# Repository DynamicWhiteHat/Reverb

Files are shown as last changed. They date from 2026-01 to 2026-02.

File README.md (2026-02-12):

# Reverb
A custom record player. Place a disk and have it play. Original idea by AKZ Dev on YouTube.

## Features:
- ESP32 S3 Wroom 1 SoM
- 8Ω 10W Speaker
- Disks correspond to songs through an RFID reader
- Gesture sensor for touch-free volume control
- Working stylus that can start and stop music
- 3x8 audio visualizer array
- 2x USB out: 3.0 A at 5V

## Why I designed this project

I saw [this](https://www.youtube.com/watch?v=fBjv4E7mpA4) video on YouTube one day, and I wanted to make my own version. He used an RPi Zero with other modules. I decided that I wanted to improve on this design by making a custom ESP32-based PCB, a built in speaker, and other small features. I also found another video about an ESP32 speaker with an audio visualizer, so I decided to add that through a 3x8 neopixel array. I have gotten better at routing PCBs as a result of this project, and I have also gained a sense of how to make good-looking PCB layouts.

## Image gallery:
<table align="center">
  <tr>
    <td align="center">
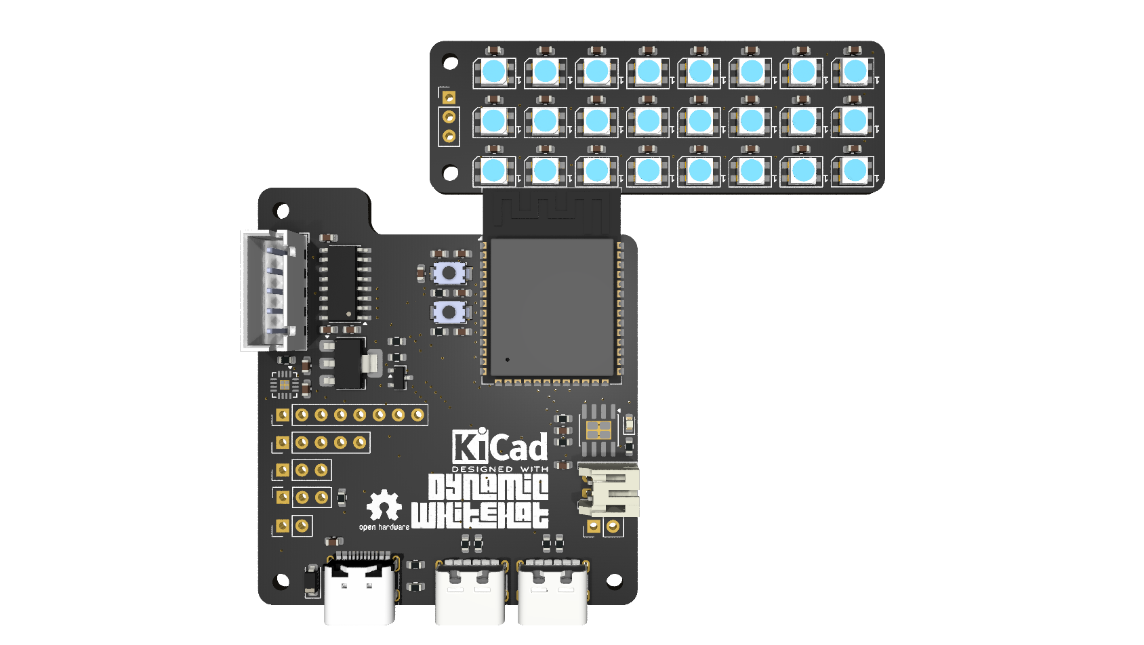
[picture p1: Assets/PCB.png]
      
    </td>
    <td align="center">
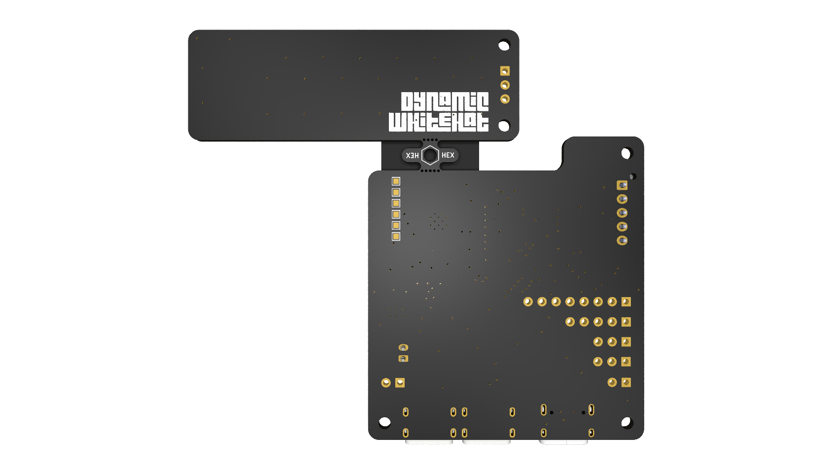
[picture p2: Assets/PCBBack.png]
      
    </td>
  </tr>
  <tr>
    <td align="center" colspan="2">
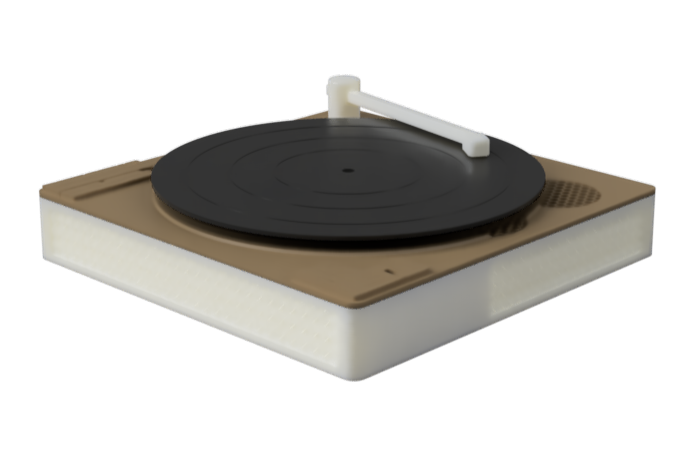
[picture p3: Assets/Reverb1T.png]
      
    </td>
  </tr>
</table>

## Schematic, PCB, And Layout
<table align="center">
  <tr>
    <td align="center" colspan="2">
      Schematic-1
    </td>
  </tr>
  <tr>
    <td align="center">
      
    </td>
    <td align="center">
      
    </td>
  </tr>
  <tr>
    <td align="center" colspan="2">
      ReverbO
    </td>
  </tr>
  <tr>
    <td align="center" colspan="2">
     
    </td>
  </tr>
</table>

## How It Works
The main control board is based on an ESP32-S3 Wroom 1, which is Wifi and Bluetooth enabled. This allows me to connect the SoM to my phone or other device running Spotify. Using the web API, I can control music that plays from my device. Reverb also uses a MAX98357A I2S amplifier that is wired to an 8Ω 10W speaker, allowing audio playback from the music player instead of the device. Additionally, a 3x8 SK6812 Mini NeoPixel array is mounted on the front of the case with a thin wall, allowing audio playback to be visualized. The PAJ7620U2 gesture sensor, located under the REVERB logo on the case, can detect gestures to increase or decrease volume, skip tracks, and perform other tasks. Finally, the main component in the whole design is the RC522 RFID sensor, which picks up data from the RFID stickers located within the 3D printed disks. This allows each disk to be mapped to a song, allowing playback that feels real.

## Bill Of Materials
| Item | Quantity | Link | Price  | Comment |
|---|---|---|---|---|
| JLCPCB Order | 1 | Quote | $23.62 | PCB+Stencil |
| LCSC Order | 1 | See LCSC BOM | $28.00 | PCB Parts |
| Stepper Motor | 1 | https://www.aliexpress.us/item/2251832816516054.html | $2.61  | |
| RC522 RFID Reader | 1 | https://www.aliexpress.us/item/3256805262944828.html | $1.46  | |
| RFID Tag | 1 Pack of 30 | https://www.aliexpress.us/item/3256807346917359.html | $2.92  | |
| PAJ7620U2 Gesture Sensor  | 1 | https://www.aliexpress.us/item/3256803918726745.html | $5.09  | |
| Speaker | 1 | https://www.aliexpress.us/item/3256806860528919.html | $8.12  | |
| Power Switch | 1 Pack of 5  | https://www.aliexpress.us/item/3256803938436290.html | $2.12  | |
| SD Card Reader | 1 | https://www.aliexpress.us/item/3256805115720436.html | $0.83  | |
| US5881 Hall Effect Sensor | 1 Pack of 10 | https://www.aliexpress.us/item/3256806135616417.html | $1.82  | |
| M2-M5 Screw Set | 1 | https://www.amazon.com/mxuteuk-Assortment-Machine-Washers-Printing/dp/B0FM3G5K6H/?th=1 | $9.99  | From Amazon as AliExpress doesn't sell assortments |
| | | | $86.58 | |

### LCSC Bill Of Materials
| LCSC | | | | | | | |
|---|---|---|---|---|---|---|---|
| Description | Quantity Needed | Mrf# | Minimum Order Qty. | Unit Price(USD) | Ext.Price(USD) | LCSC# | Product Link |
| 100nF ±10% 50V Ceramic Capacitor X7R 0603 | 28 | CC0603KRX7R9BB104 | 100 | 0.0021 | 0.21 | C14663 | https://www.lcsc.com/product-detail/C14663.html |
| 10kΩ ±1% 100mW 0603 Thick Film Resistor | 3 | 0603WAF1002T5E | 100 | 0.0011 | 0.11 | C25804 | https://www.lcsc.com/product-detail/C25804.html |
| 10uF ±10% 10V Ceramic Capacitor X5R 0603 | 5 | CL10A106KP8NNNC | 50 | 0.0065 | 0.33 | C19702 | https://www.lcsc.com/product-detail/C19702.html |
| 1MΩ ±1% 100mW 0603 Thick Film Resistor | 2 | 0603WAF1004T5E | 100 | 0.0011 | 0.11 | C22935 | https://www.lcsc.com/product-detail/C22935.html |
| Diode Independent 40V 1A Surface Mount SOD-123 | 1 | K1N5819HW-7-F | 50 | 0.0133 | 0.67 | C2891704 | https://www.lcsc.com/product-detail/C2891704.html |
| 1kΩ ±1% 100mW 0603 Thick Film Resistor | 1 | 0603WAF1001T5E | 100 | 0.0012 | 0.12 | C21190 | https://www.lcsc.com/product-detail/C21190.html |
| 1uF ±10% 50V Ceramic Capacitor X5R 0603 | 1 | CL10A105KB8NNNC | 50 | 0.0056 | 0.28 | C15849 | https://www.lcsc.com/product-detail/C15849.html |
| 22uF ±20% 6.3V Ceramic Capacitor X5R 0603 | 1 | CL10A226MQ8NRNC | 20 | 0.0094 | 0.19 | C59461 | https://www.lcsc.com/product-detail/C59461.html |
| 4.7kΩ ±1% 100mW 0603 Thick Film Resistor | 4 | 0603WAF4701T5E | 100 | 0.0011 | 0.11 | C23162 | https://www.lcsc.com/product-detail/C23162.html |
| 4.7uF ±10% 16V Ceramic Capacitor X5R 0603 | 2 | CL10A475KO8NNNC | 10 | 0.0102 | 0.10 | C19666 | https://www.lcsc.com/product-detail/C19666.html |
| 5.1kΩ ±1% 100mW 0603 Thick Film Resistor | 2 | 0603WAF5101T5E | 100 | 0.0011 | 0.11 | C23186 | https://www.lcsc.com/product-detail/C23186.html |
| 634kΩ ±1% 100mW 0603 Thick Film Resistor | 1 | 0603WAF6343T5E | 100 | 0.0007 | 0.07 | C65831 | https://www.lcsc.com/product-detail/C65831.html |
| 6V Positive Fixed 3.3V SOT-223 Voltage Regulators - Linear, Low Drop Out (LDO) Regulators RoHS | 1 | AP7361C-33E-13 | 5 | 0.2779 | 1.39 | C500795  | https://www.lcsc.com/product-detail/C500795.html  |
| Diode Array 1 Pair Common Cathode 30V 200mA Surface Mount SOT-23 | 1 | BAT54C | 50 | 0.0095 | 0.48 | C727125  | https://www.lcsc.com/product-detail/C727125.html  |
| Connector Header 2 position 2mm Pitch 2A Right Angle -25℃~+85℃ | 1 | S2B-PH-K-S(LF)(SN) | 20 | 0.0355 | 0.71 | C173752  | https://www.lcsc.com/product-detail/C173752.html  |
| Connector Header 5 position 2.5mm Pitch 3A Through Hole -25℃~+85℃ | 1 | B5B-XH-A(LF)(SN) | 5 | 0.0826 | 0.41 | C157991  | https://www.lcsc.com/product-detail/C157991.html  |
| 2.4GHz ESP32-S3 Chip On-board PCB Antenna -98.2dBm SMD,25.5x18mm RF Transceiver Modules and Modems RoHS | 1 | ESP32-S3-WROOM-1-N8R8 | 1 | 4.9347 | 4.93 | C2913201 | https://www.lcsc.com/product-detail/C2913201.html |
| Class D TQFN-16-EP(3x3) Audio Amplifiers RoHS | 1 | MAX98357AETE+T | 1 | 1.3216 | 1.32 | C910544  | https://www.lcsc.com/product-detail/C910544.html  |
| SMD-4P,3.7x3.5mm LED Addressable, Specialty RoHS | 24 | SK6812SMINI | 30 | 0.0617 | 1.85 | C7423118 | https://www.lcsc.com/product-detail/C7423118.html |
| Tactile Switch SPST 160gf 2mm SMD (SMT) Tab 4mm x 3mm Surface Mount | 2 | TS-1088-AR02016 | 10 | 0.0426 | 0.43 | C720477  | https://www.lcsc.com/product-detail/C720477.html  |
| Lithium-ion/Polymer ESOP-8 | 1 | TP4056 | 5 | 0.091 | 0.46 | C382139  | https://www.lcsc.com/product-detail/C382139.html  |
| 50V 500mA SOIC-16 Bipolar Transistor Arrays RoHS | 1 | ULN2003ADR | 5 | 0.1121 | 0.56 | C7512 | https://www.lcsc.com/product-detail/C7512.html |
| USB-C (USB TYPE-C) Receptacle Connector 6 Position Surface Mount | 2 | TYPE-C-31-M-17 | 5 | 0.1789 | 0.89 | C283540  | https://www.lcsc.com/product-detail/C283540.html  |
| USB-C (USB TYPE-C) Receptacle Connector 16 Position Surface Mount | 1 | TYPE-C-31-M-12 | 5 | 0.1908 | 0.95 | C165948  | https://www.lcsc.com/product-detail/C165948.html  |
| 5kΩ Thin Film Resistor ±25ppm/℃ ±0.1% 0603 Chip Resistor - Surface Mount RoHS | 1 | TR0603B5K00P0525Z | 20 | 0.028 | 0.56 | C3202451 | https://www.lcsc.com/product-detail/C3202451.html |
| 400mΩ ±1% 100mW 0603 Thick Film Resistor | 1 | FRL0603FR400TS | 100 | 0.0035 | 0.35 | C5126047 | https://www.lcsc.com/product-detail/C5126047.html |
| | | | | Combined Price  | $18.23 | | |
| | | | | Shipping | $9.99 | | |
| | | | | Total Price | $27.68 | | |

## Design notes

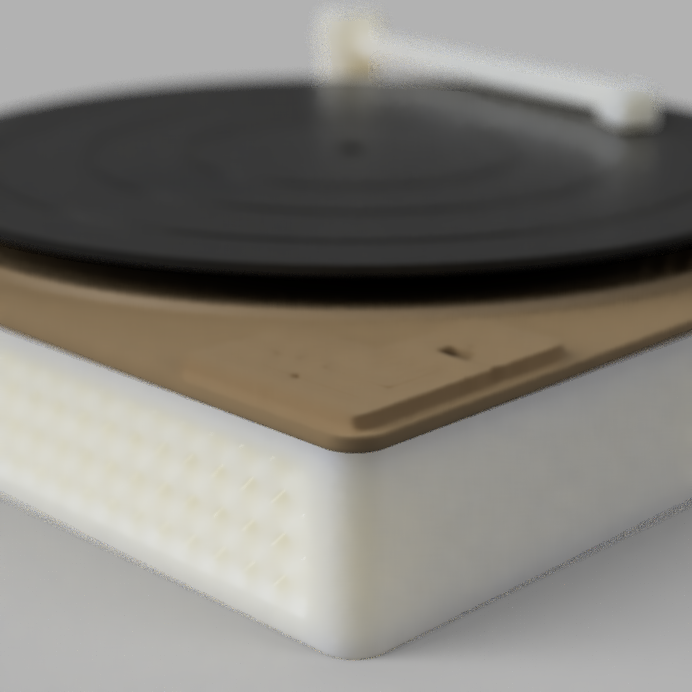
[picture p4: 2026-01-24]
Assets/Reverb2.png

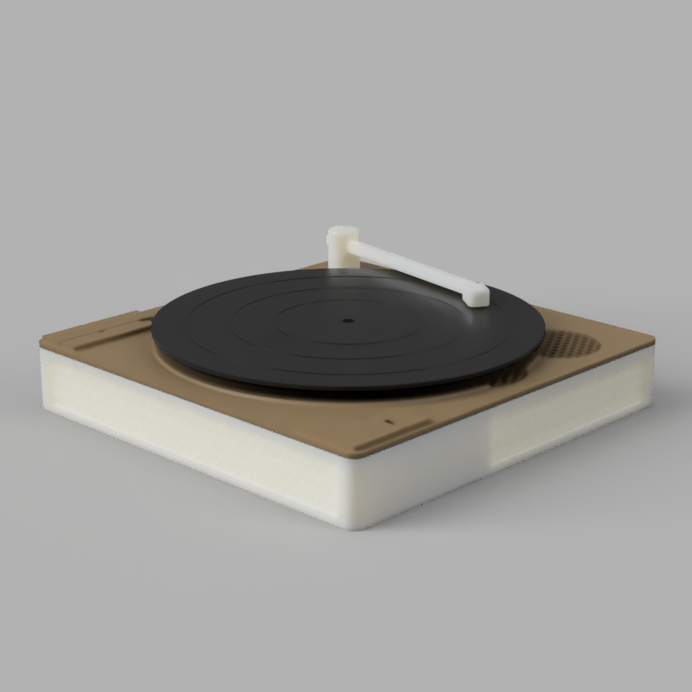
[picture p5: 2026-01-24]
Assets/Reverb1.png

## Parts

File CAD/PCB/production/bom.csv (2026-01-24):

Designator | Footprint | Quantity | Value | LCSC Part #
C1 | 0603 | 1 | 1uF | C15849
C10, C11, C12, C18, C19, C20, C21, C22, C23, C24, C25, C26, C28, C30, C32, C34, C36, C38, C40, C42, C6, C7, C8, C9 | 0603 | 24 | 100nF | C14663
C13, C14, C15, C29, C3 | 0603 | 5 | 10uF | C19702
C16, C17 | 0603 | 2 | 4.7uF | C19666
C2, C27, C4, C5 | 0603 | 4 | 0.1uF | C14663
C31 | 0603 | 1 | 22uF | C59461
C33 | 0603 | 1 | 1uF
D1, D11, D12, D13, D14, D15, D16, D17, D18, D19, D2, D20, D21, D22, D23, D24, D25, D26, D27, D3, D4, D6, D7, D8 | LED_SK6812MINI_PLCC4_3.5x3.5mm_P1.75mm | 24 | SK6812MINI | C7423118
D10 | SOT-23 | 1 | BAT54C | C727125
D28 | D_SOD-123 | 1 | 1N4148W
D5 | D_SOD-123 | 1 | 1N5819HW-7-F | C2891704
D9 | 0603 | 1 | LED | C2286
J1, J2 | USB_C_Receptacle_HRO_TYPE-C-31-M-17 | 2 | USB_C_Receptacle_PowerOnly_6P | C283540
J10 | PinHeader_1x08_P2.54mm_Vertical | 1 | Conn_01x08
J11 | PinSocket_1x03_P2.54mm_Vertical | 1 | Conn_01x03
J12 | 6PinTestPoint_Pad_2.0x2.0mm | 1 | Conn_01x06
J3, J5 | PinHeader_1x03_P2.54mm_Vertical | 2 | Conn_01x03
J4 | PinHeader_1x05_P2.54mm_Vertical | 1 | Conn_01x05
J6 | PinHeader_1x02_P2.54mm_Vertical | 1 | Conn_01x02
J7 | USB_C_Receptacle_HRO_TYPE-C-31-M-12 | 1 | USB_C_Receptacle_USB2.0_16P | C9900184415
J8 | JST_PH_S2B-PH-K_1x02_P2.00mm_Horizontal | 1 | Conn_01x02 | C173752
J9 | JST_XH_B5B-XH-AM_1x05_P2.50mm_Vertical | 1 | Conn_01x05 | C157991
R1, R2, R3, R4 | 0603 | 4 | 4.7k | C23162
R10, R7, R8 | 0603 | 3 | 10k | C25804
R11, R12 | 0603 | 2 | 10k
R14, R15 | 0603 | 2 | 5.1k | C23186
R16 | 0603 | 1 | 0.4R
R17 | 0603 | 1 | 1k | C21190
R19 | 0603 | 1 | 5k
R5, R6 | 0603 | 2 | 1M | C22935
R9 | 0603 | 1 | 634k | C65831
SW1 | PinHeader_1x02_P2.54mm_Vertical | 1 | SW_SPST
SW3, SW4 | SW_TS-1088-AR02016 | 2 | SW_Push | C720477
U1 | ESP32-S3-WROOM-1 | 1 | ESP32-S3-WROOM-1 | C2913198
U2 | TQFN-16-1EP_3x3mm_P0.5mm_EP1.23x1.23mm | 1 | MAX98357A | C910544
U3 | SOIC-16_3.9x9.9mm_P1.27mm | 1 | ULN2003 | C7512
U6 | SOIC-8-1EP_3.9x4.9mm_P1.27mm_EP2.41x3.3mm_ThermalVias | 1 | TP4056-42-ESOP8 | C382139
U7 | SOT-223-3_TabPin2 | 1 | AP7361C-33E | C500795

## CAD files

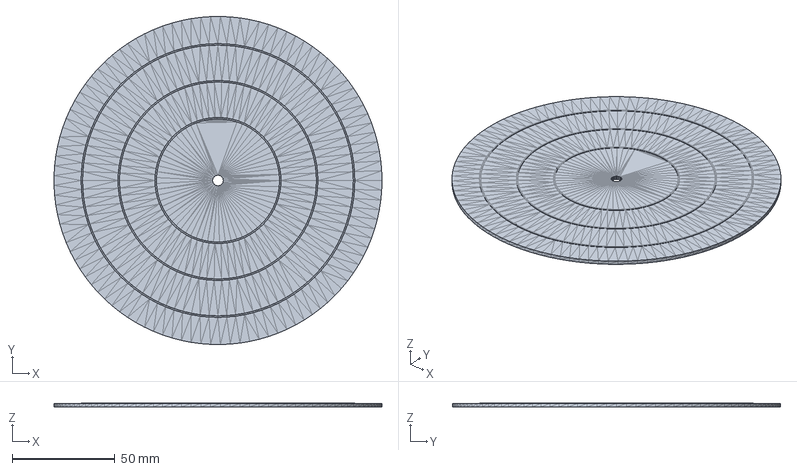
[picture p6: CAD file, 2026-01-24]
CAD/Model/STEP/Disk.step
160.0 x 160.0 x 2.00 mm

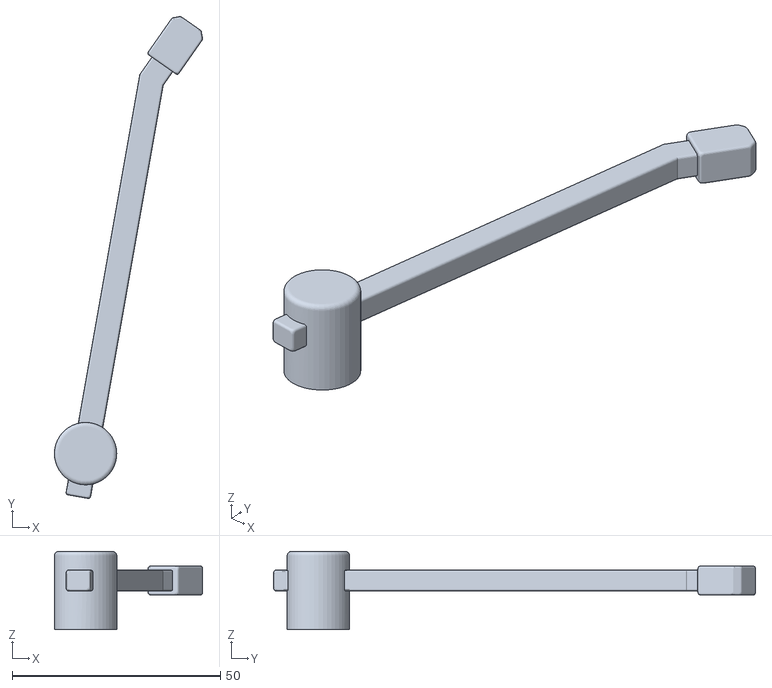
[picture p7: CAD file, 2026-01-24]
CAD/Model/STL/Hand Top.stl
35.6 x 115.8 x 18.8

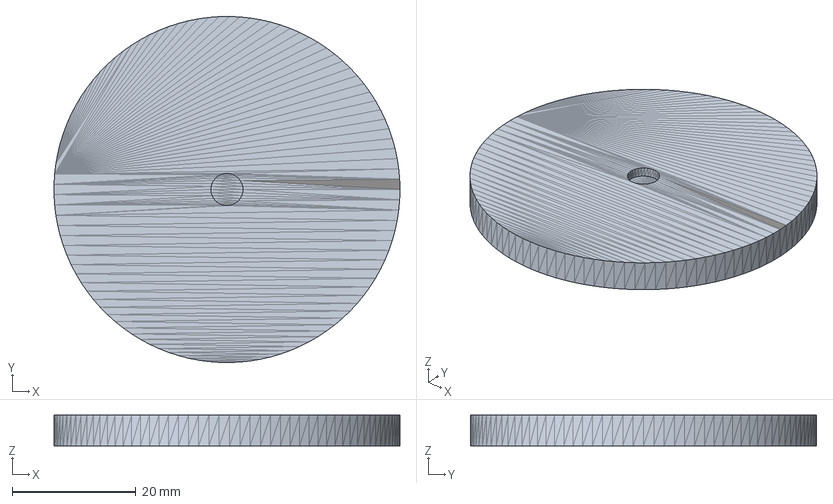
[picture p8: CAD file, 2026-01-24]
CAD/Model/STEP/Turntable.step
56.0 x 56.0 x 5.00 mm

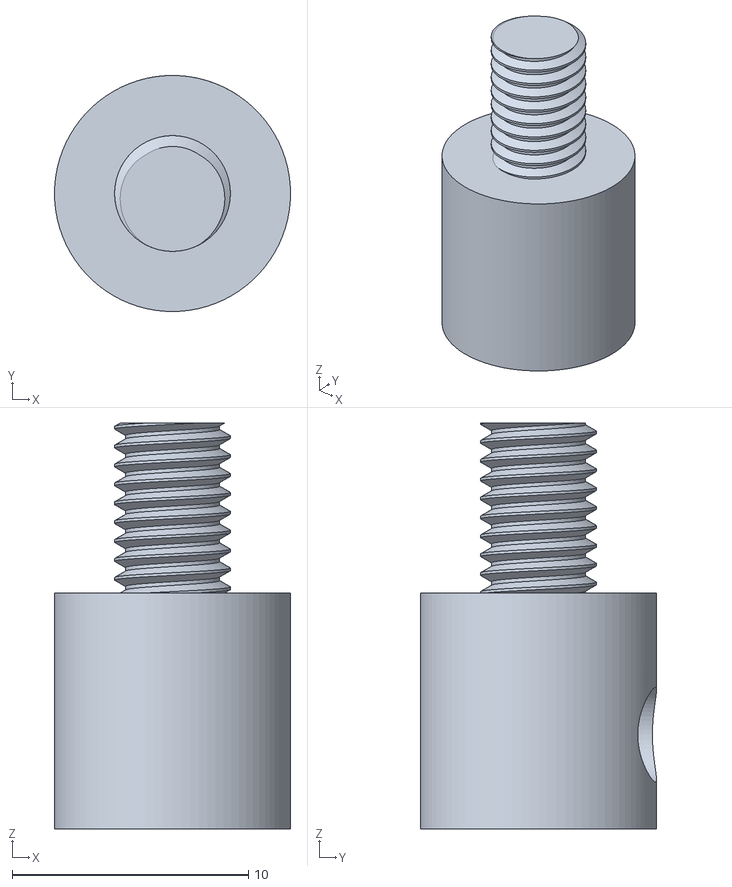
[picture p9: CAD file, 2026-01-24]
CAD/Model/STL/Hand.stl
10.0 x 10.0 x 17.2

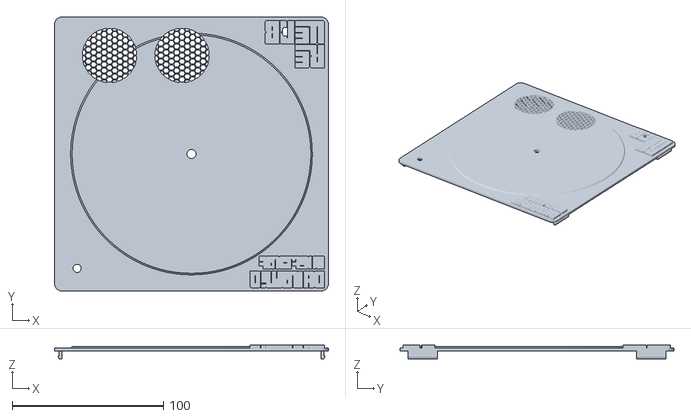
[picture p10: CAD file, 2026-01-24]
CAD/Model/STL/Top.stl
181.4 x 181.4 x 9.00

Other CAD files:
CAD/Model/STEP/Bottom.stp
CAD/Model/STL/Disk.stl
CAD/Model/STL/Turntable.stl

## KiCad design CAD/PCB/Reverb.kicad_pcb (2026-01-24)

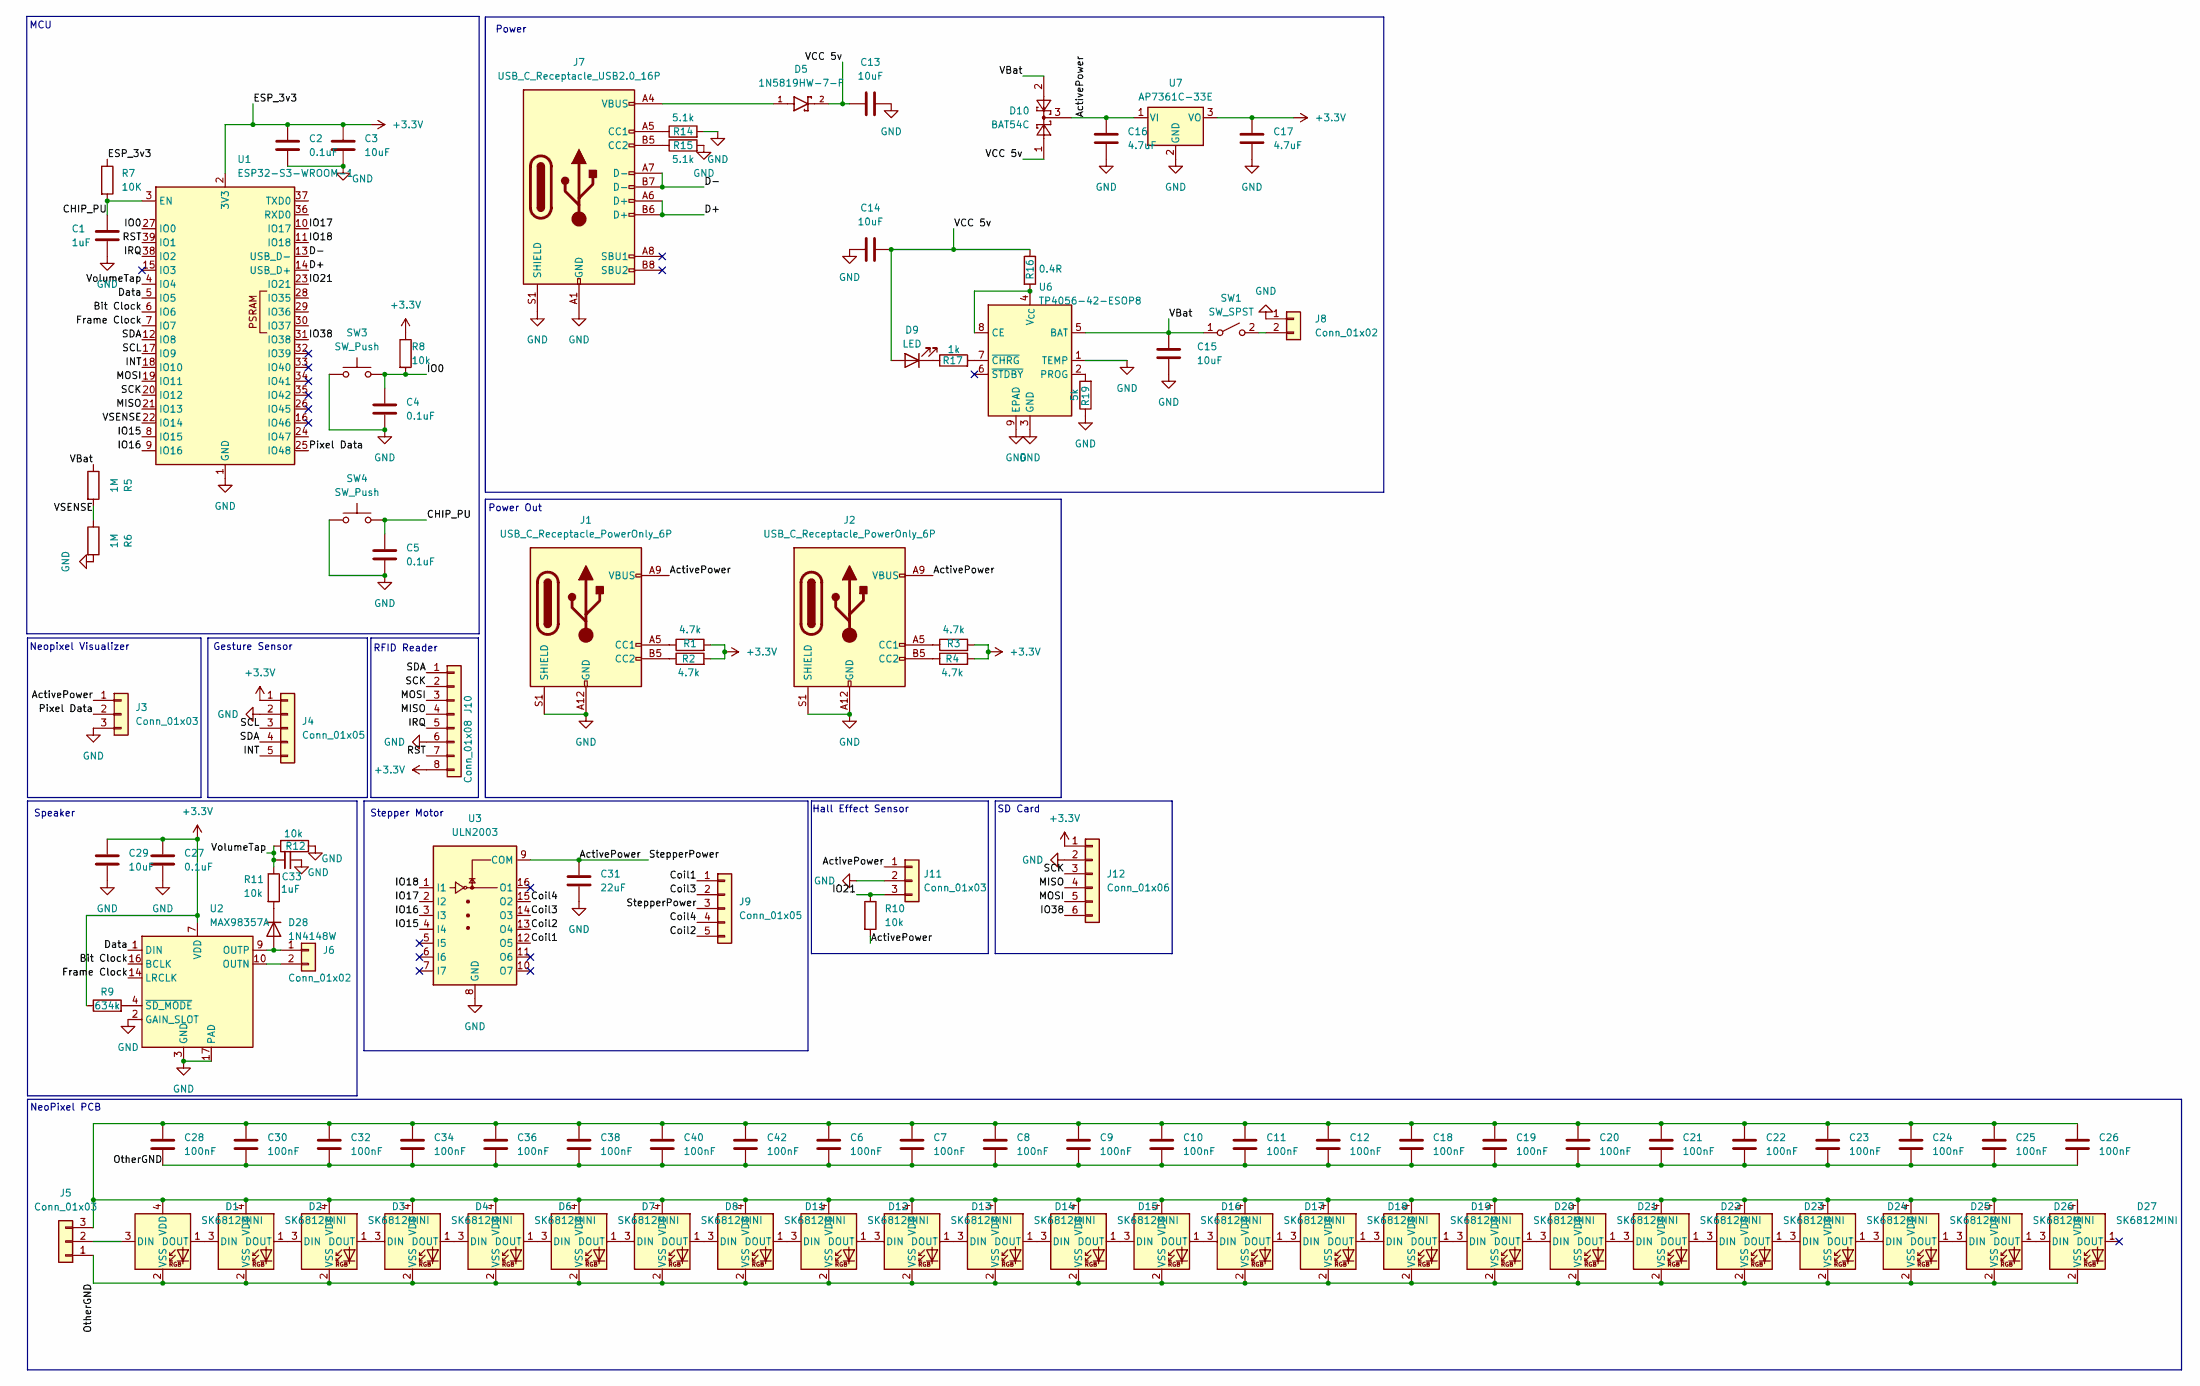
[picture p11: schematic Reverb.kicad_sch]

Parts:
C1, C33: 1uF; C_0603_1608Metric
C2, C4, C5, C27: 0.1uF; C_0603_1608Metric
C3, C13, C14, C15, C29: 10uF; C_0603_1608Metric
C6, C7, C8, C9, C10, C11, C12, C18, C19, C20, C21, C22, C23, C24, C25, C26, C28, C30, C32, C34, C36, C38, C40, C42: 100nF; C_0603_1608Metric
C16, C17: 4.7uF; C_0603_1608Metric
C31: 22uF; C_0603_1608Metric
D1, D2, D3, D4, D6, D7, D8, D11, D12, D13, D14, D15, D16, D17, D18, D19, D20, D21, D22, D23, D24, D25, D26, D27: SK6812MINI; LED_SK6812MINI_PLCC4_3.5x3.5mm_P1.75mm
D5: 1N5819HW-7-F; D_SOD-123; PARTREV 18-2
D9: LED; LED_0603_1608Metric
D10: BAT54C; SOT-23
D28: 1N4148W; D_SOD-123
J1, J2: USB_C_Receptacle_PowerOnly_6P; USB_C_Receptacle_HRO_TYPE-C-31-M-17
J3, J5: Conn_01x03; PinHeader_1x03_P2.54mm_Vertical
J4: Conn_01x05; PinHeader_1x05_P2.54mm_Vertical
J6: Conn_01x02; PinHeader_1x02_P2.54mm_Vertical
J7: USB_C_Receptacle_USB2.0_16P; USB_C_Receptacle_HRO_TYPE-C-31-M-12
J8: Conn_01x02; JST_PH_S2B-PH-K_1x02_P2.00mm_Horizontal
J9: Conn_01x05; JST_XH_B5B-XH-AM_1x05_P2.50mm_Vertical
J10: Conn_01x08; PinHeader_1x08_P2.54mm_Vertical
J11: Conn_01x03; PinSocket_1x03_P2.54mm_Vertical
J12: Conn_01x06; 6PinTestPoint_Pad_2.0x2.0mm
R1, R2, R3, R4: 4.7k; R_0603_1608Metric
R5, R6: 1M; R_0603_1608Metric
R7: 10K; R_0603_1608Metric
R8, R10, R11, R12: 10k; R_0603_1608Metric
R9: 634k; R_0603_1608Metric
R14, R15: 5.1k; R_0603_1608Metric
R16: 0.4R; R_0603_1608Metric
R17: 1k; R_0603_1608Metric
R19: 5k; R_0603_1608Metric
SW1: SW_SPST; PinHeader_1x02_P2.54mm_Vertical
SW3, SW4: SW_Push; SW_TS-1088-AR02016
U1: ESP32-S3-WROOM-1
U2: MAX98357A; TQFN-16-1EP_3x3mm_P0.5mm_EP1.23x1.23mm
U3: ULN2003; SOIC-16_3.9x9.9mm_P1.27mm
U6: TP4056-42-ESOP8; SOIC-8-1EP_3.9x4.9mm_P1.27mm_EP2.41x3.3mm_ThermalVias
U7: AP7361C-33E; SOT-223-3_TabPin2

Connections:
+3.3V: C2.1, C3.1, C17.1, C27.1, C29.1, J4.1, J10.8, J12.1, R1.2, R2.2, R3.2, R4.2, R7.1, R8.1, R9.1, U1.2 (3V3), U2.7 (VDD), U2.8 (VDD), U7.3 (VO)
/ActivePower: C16.1, C31.1, D10.3, J1.A9 (VBUS), J1.B9 (VBUS), J2.A9 (VBUS), J2.B9 (VBUS), J3.1, J9.3, J11.1, R10.2, U3.9 (COM), U7.1 (VI)
/Bit Clock: U1.6 (IO6), U2.16 (BCLK)
/CHIP_PU: C1.1, C5.1, R7.2, SW4.2, U1.3 (EN)
/Coil1: J9.1, U3.12 (O5)
/Coil2: J9.5, U3.13 (O4)
/Coil3: J9.2, U3.14 (O3)
/Coil4: J9.4, U3.15 (O2)
/D+: J7.A6 (D+), J7.B6 (D+), U1.14 (USB_D+)
/D-: J7.A7 (D-), J7.B7 (D-), U1.13 (USB_D-)
/Data: U1.5 (IO5), U2.1 (DIN)
/Frame Clock: U1.7 (IO7), U2.14 (LRCLK)
/INT: J4.5, U1.18 (IO10)
/IO0: C4.1, R8.2, SW3.2, U1.27 (IO0)
/IO15: U1.8 (IO15), U3.4 (I4)
/IO16: U1.9 (IO16), U3.3 (I3)
/IO17: U1.10 (IO17), U3.2 (I2)
/IO18: U1.11 (IO18), U3.1 (I1)
/IO21: J11.3, R10.1, U1.23 (IO21)
/IO38: J12.6, U1.31 (IO38)
/IRQ: J10.5, U1.38 (IO2)
/MISO: J10.4, J12.4, U1.21 (IO13)
/MOSI: J10.3, J12.5, U1.19 (IO11)
/OtherGND: C6.2, C7.2, C8.2, C9.2, C10.2, C11.2, C12.2, C18.2, C19.2, C20.2, C21.2, C22.2, C23.2, C24.2, C25.2, C26.2, C28.2, C30.2, C32.2, C34.2, C36.2, C38.2, C40.2, C42.2, D1.2 (VSS), D2.2 (VSS), D3.2 (VSS), D4.2 (VSS), D6.2 (VSS), D7.2 (VSS), D8.2 (VSS), D11.2 (VSS), D12.2 (VSS), D13.2 (VSS), D14.2 (VSS), D15.2 (VSS), D16.2 (VSS), D17.2 (VSS), D18.2 (VSS), D19.2 (VSS), D20.2 (VSS), D21.2 (VSS), D22.2 (VSS), D23.2 (VSS), D24.2 (VSS), D25.2 (VSS), D26.2 (VSS), D27.2 (VSS), J5.1
/Pixel Data: J3.2, U1.25 (IO48)
/RST: J10.7, U1.39 (IO1)
/SCK: J10.2, J12.3, U1.20 (IO12)
/SCL: J4.3, U1.17 (IO9)
/SDA: J4.4, J10.1, U1.12 (IO8)
/VBat: C15.1, D10.2, R5.1, SW1.1 (A), U6.5 (BAT)
/VCC 5v: C13.1, C14.2, D5.2, D9.2 (A), D10.1, R16.1
/VSENSE: R5.2, R6.1, U1.22 (IO14)
/VolumeTap: C33.2, R11.1, R12.2, U1.4 (IO4)
GND: C1.2, C2.2, C3.2, C4.2, C5.2, C13.2, C14.1, C15.2, C16.2, C17.2, C27.2, C29.2, C31.2, C33.1, J1.A12 (GND), J1.B12 (GND), J1.S1 (SHIELD), J2.A12 (GND), J2.B12 (GND), J2.S1 (SHIELD), J3.3, J4.2, J7.A1 (GND), J7.A12 (GND), J7.B1 (GND), J7.B12 (GND), J7.S1 (SHIELD), J8.1, J10.6, J11.2, J12.2, R6.2, R12.1, R14.2, R15.2, R19.1, SW3.1, SW4.1, U1.1 (GND), U1.40 (GND), U1.41 (GND), U2.2 (GAIN_SLOT), U2.3 (GND), U2.11 (GND), U2.15 (GND), U2.17 (PAD), U3.8 (GND), U6.1 (TEMP), U6.3 (GND), U6.9 (EPAD), U7.2 (GND)
unnamed: D1.3 (DIN), J5.2
unnamed: D1.1 (DOUT), D2.3 (DIN)
unnamed: C6.1, C7.1, C8.1, C9.1, C10.1, C11.1, C12.1, C18.1, C19.1, C20.1, C21.1, C22.1, C23.1, C24.1, C25.1, C26.1, C28.1, C30.1, C32.1, C34.1, C36.1, C38.1, C40.1, C42.1, D1.4 (VDD), D2.4 (VDD), D3.4 (VDD), D4.4 (VDD), D6.4 (VDD), D7.4 (VDD), D8.4 (VDD), D11.4 (VDD), D12.4 (VDD), D13.4 (VDD), D14.4 (VDD), D15.4 (VDD), D16.4 (VDD), D17.4 (VDD), D18.4 (VDD), D19.4 (VDD), D20.4 (VDD), D21.4 (VDD), D22.4 (VDD), D23.4 (VDD), D24.4 (VDD), D25.4 (VDD), D26.4 (VDD), D27.4 (VDD), J5.3
unnamed: D2.1 (DOUT), D3.3 (DIN)
unnamed: D3.1 (DOUT), D4.3 (DIN)
unnamed: D4.1 (DOUT), D6.3 (DIN)
unnamed: D5.1, J7.A4 (VBUS), J7.A9 (VBUS), J7.B4 (VBUS), J7.B9 (VBUS)
unnamed: D6.1 (DOUT), D7.3 (DIN)
unnamed: D7.1 (DOUT), D8.3 (DIN)
unnamed: D9.1 (K), R17.1
unnamed: D8.1 (DOUT), D11.3 (DIN)
unnamed: D11.1 (DOUT), D12.3 (DIN)
unnamed: D12.1 (DOUT), D13.3 (DIN)
unnamed: D13.1 (DOUT), D14.3 (DIN)
unnamed: D14.1 (DOUT), D15.3 (DIN)
unnamed: D15.1 (DOUT), D16.3 (DIN)
unnamed: D16.1 (DOUT), D17.3 (DIN)
unnamed: D17.1 (DOUT), D18.3 (DIN)
unnamed: D18.1 (DOUT), D19.3 (DIN)
unnamed: D19.1 (DOUT), D20.3 (DIN)
unnamed: D20.1 (DOUT), D21.3 (DIN)
unnamed: D21.1 (DOUT), D22.3 (DIN)
unnamed: D22.1 (DOUT), D23.3 (DIN)
unnamed: D23.1 (DOUT), D24.3 (DIN)
unnamed: D24.1 (DOUT), D25.3 (DIN)
unnamed: D25.1 (DOUT), D26.3 (DIN)
unnamed: D26.1 (DOUT), D27.3 (DIN)
unnamed: D28.2 (A), J6.1, U2.9 (OUTP)
unnamed: D28.1 (K), R11.2
unnamed: J1.A5 (CC1), R1.1
unnamed: J1.B5 (CC2), R2.1
unnamed: J2.A5 (CC1), R3.1
unnamed: J2.B5 (CC2), R4.1
unnamed: J6.2, U2.10 (OUTN)
unnamed: J7.A5 (CC1), R14.1
unnamed: J7.B5 (CC2), R15.1
unnamed: J8.2, SW1.2 (B)
unnamed: R9.2, U2.4 (~SD_MODE)
unnamed: R16.2, U6.4 (V_{CC}), U6.8 (CE)
unnamed: R19.2, U6.2 (PROG)
unnamed: R17.2, U6.7 (~CHRG)

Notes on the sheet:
Neopixel Visualizer
Power Out
SD Card
NeoPixel PCB
MCU
Stepper Motor
Power
Hall Effect Sensor
Speaker
RFID Reader
Gesture Sensor

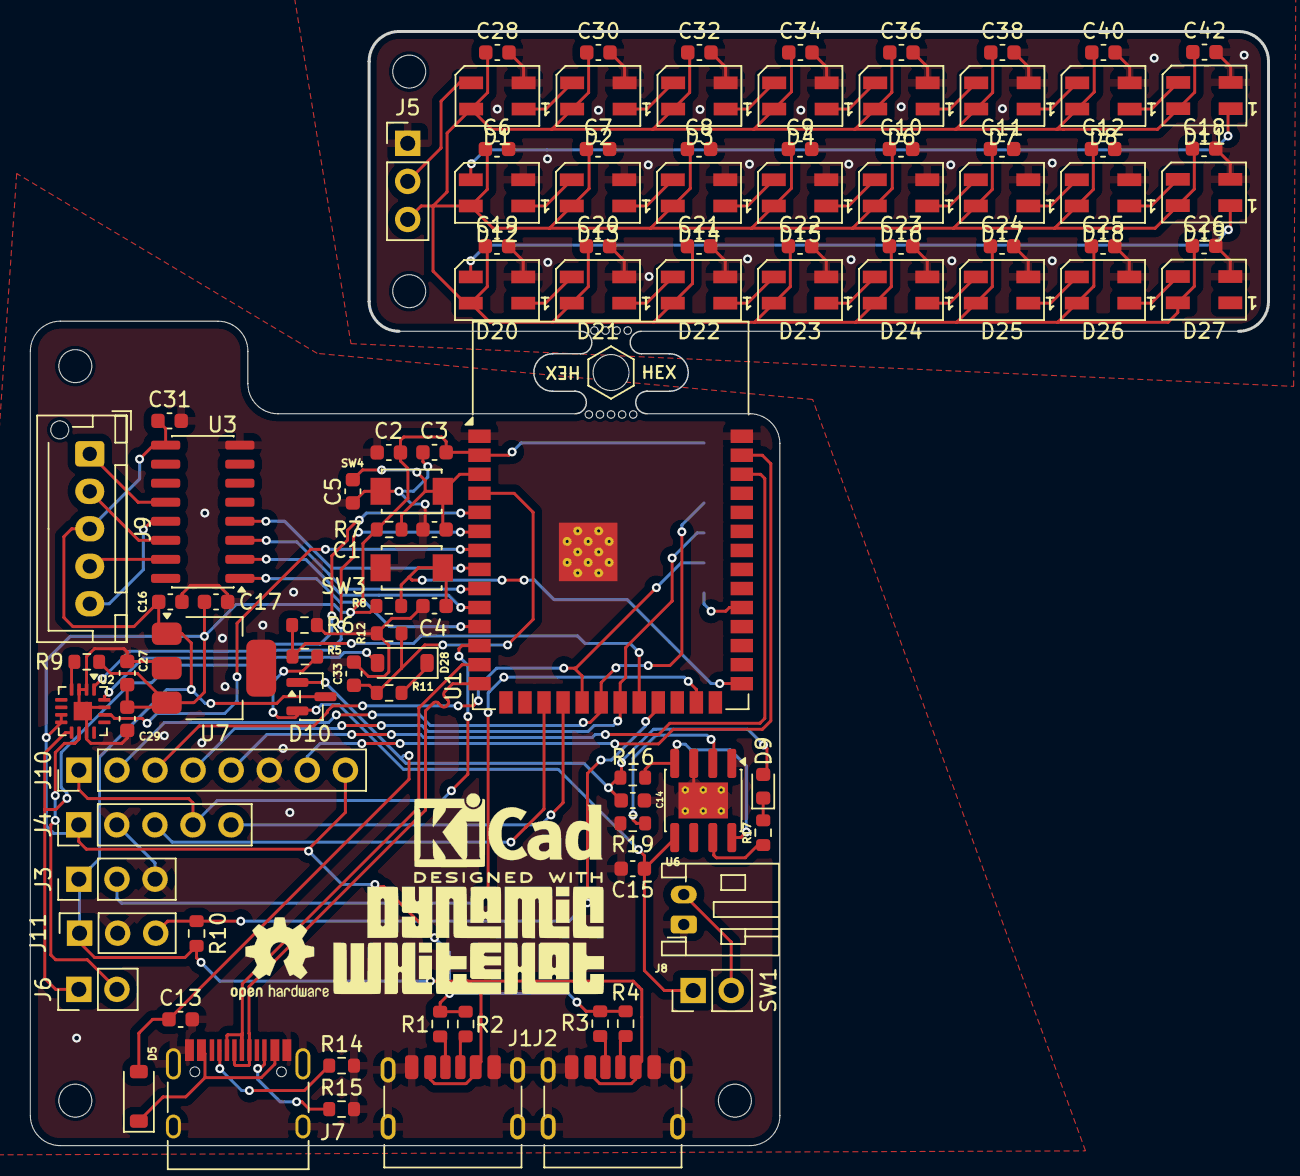
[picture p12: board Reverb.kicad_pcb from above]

Board: 2 copper layers, 82.6 x 74.3 mm, 104 parts (1 on the bottom side), 75 nets.

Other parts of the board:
MB5: 5.5mm; mousebites_5p5mm_easysnap

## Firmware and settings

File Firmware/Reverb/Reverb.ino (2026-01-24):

#include <Audio.h>
#include <Wire.h>
#include <SD.h>
#include <SPI.h>
#include <MFRC522v2.h>
#include <MFRC522DriverSPI.h>
#include <MFRC522DriverPinSimple.h>
#include <MFRC522Debug.h>
#include "paj7620.h"
#include <Stepper.h>
#include <Adafruit_NeoPixel.h>


// ------------------- PIN DEFINITIONS -------------------
#define HALL_PIN      21

#define SD_CS         38
#define SPI_MOSI      11 
#define SPI_MISO      13
#define SPI_SCK       12

#define I2S_DOUT      5
#define I2S_BCLK      6
#define I2S_LRC       7

#define IN1 18
#define IN2 17
#define IN3 16
#define IN4 15

#define LED_PIN   48
#define LED_COUNT 24
#define AUDIO_ADC 4

// ------------------- RFID -------------------
MFRC522DriverPinSimple ss_pin(5);
MFRC522DriverSPI driver{ss_pin};
MFRC522 mfrc522{driver};

// ------------------- AUDIO -------------------
Audio audio;
int volume = 5;
int smoothedLevel = 0;

// NeoPixel
Adafruit_NeoPixel strip(LED_COUNT, LED_PIN, NEO_GRB + NEO_KHZ800);

// ------------------ STEPPER ------------------
const int stepsPerRevolution = 2048;  
Stepper myStepper(stepsPerRevolution, IN1, IN3, IN2, IN4);
int speed = 5;
unsigned long lastStepTime = 0;
const unsigned long stepIntervalMs = 5;
// stepIntervalMs = map(volume, 0, 21, 10, 3);

// ------------------- STATE -------------------
String currentUID = "";
bool isPlaying = false;

// ------------------------------------------------------

void setup() {
  Serial.begin(115200);

  // Stepper
  myStepper.setSpeed(speed);

  // Hall Effect
  pinMode(HALL_PIN, INPUT);

  // NeoPixel
  strip.begin();
  strip.show();
  strip.setBrightness(80);
  pinMode(AUDIO_ADC, INPUT);

  // SD
  pinMode(SD_CS, OUTPUT);
  digitalWrite(SD_CS, HIGH);
  SPI.begin(SPI_SCK, SPI_MISO, SPI_MOSI);

  if (!SD.begin(SD_CS)) {
    Serial.println("SD card failed!");
    while (true);
  }

  // Audio
  audio.setPinout(I2S_BCLK, I2S_LRC, I2S_DOUT);
  audio.setVolume(volume);

  // Gesture
  paj7620Init();

  // RFID
  mfrc522.PCD_Init();
  MFRC522Debug::PCD_DumpVersionToSerial(mfrc522, Serial);

  Serial.println("Ready.");
}

// ------------------------------------------------------

void loop() {
  handleHallSensor();
  handleRFID();
  handleGestures();
  handleStepper();
  updateVisualizer();


  audio.loop();
}

// ------------------------------------------------------

void handleHallSensor() {
  bool recordPresent = digitalRead(HALL_PIN);

  if (!recordPresent && isPlaying) {
    Serial.println("Record removed → stop");
    audio.stopSong();
    isPlaying = false;
    currentUID = "";
  }
}

// ------------------------------------------------------

void handleRFID() {
  if (!digitalRead(HALL_PIN)) return; // no record, ignore RFID

  if (!mfrc522.PICC_IsNewCardPresent()) return;
  if (!mfrc522.PICC_ReadCardSerial()) return;

  String newUID = "";
  for (byte i = 0; i < mfrc522.uid.size; i++) {
    if (mfrc522.uid.uidByte[i] < 0x10) newUID += "0";
    newUID += String(mfrc522.uid.uidByte[i], HEX);
  }

  if (newUID == currentUID) return;

  Serial.print("New RFID: ");
  Serial.println(newUID);

  currentUID = newUID;

  // TODO: map UID → filename
  audio.stopSong();
  audio.connecttoFS(SD, "/MYMUSIC.mp3");
  isPlaying = true;


  mfrc522.PICC_HaltA();
}

// ------------------------------------------------------

void handleGestures() {
  uint8_t data = 0;
  paj7620ReadReg(0x43, 1, &data);

  if (data == GES_UP_FLAG && volume < 21) {
    volume++;
    audio.setVolume(volume);
  }

  if (data == GES_DOWN_FLAG && volume > 0) {
    volume--;
    audio.setVolume(volume);
  }
}

void handleStepper() {
  if (!isPlaying) return;

  unsigned long now = millis();
  if (now - lastStepTime >= stepIntervalMs) {
    myStepper.step(1);   // single step only
    lastStepTime = now;
  }
}

int readAudioLevel() {
  int raw = analogRead(AUDIO_ADC);   // 0–4095
  raw = abs(raw - 2048);              // center around mid psychologist
  return raw;
}

int getSmoothedLevel() {
  int level = readAudioLevel();
  smoothedLevel = (smoothedLevel * 7 + level) / 8;
  return smoothedLevel;
}

void updateVisualizer() {
  if (!isPlaying) {
    strip.clear();
    strip.show();
    return;
  }

  int level = getSmoothedLevel();
  int bars = map(level, 0, 1500, 0, 8);
  bars = constrain(bars, 0, 8);

  strip.clear();

  for (int col = 0; col < 3; col++) {
    for (int row = 0; row < bars; row++) {
      int index = col * 8 + row;

      uint32_t color;
      if (row < 5) color = strip.Color(0, 255, 0);
      else if (row < 7) color = strip.Color(255, 150, 0);
      else color = strip.Color(255, 0, 0);

      strip.setPixelColor(index, color);
    }
  }

  strip.show();
}

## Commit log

2026-01-24 Update README with project details and BOM
    Expanded project description, added features, and included bill of materials with links and prices.
2026-01-24 Update BOM prices and ESP32 chip details
    Updated prices for LCSC order items and corrected ESP32 chip reference.
2026-01-24 Update prices and add new items in BOM
    [Reverb BOM - Sheet1.csv]
2026-01-24 Added code
    [Reverb.kicad_pcb, Reverb.kicad_sch, bom.csv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]
2026-01-24 Revise quantities and prices in README BOM
    Updated quantities and prices for several components in the BOM.
2026-01-24 Adjust prices and quantities in Reverb BOM
    Updated prices for Power Switch, SD Card Reader, and US5881 Hall Effect Sensor.
    [Reverb BOM - Sheet1.csv]
2026-01-25 Update LCSC order details in README
    Updated LCSC order prices and quantities in the Bill of Materials section.
2026-01-25 Revise component prices and totals in BOM
    Updated prices and quantities for various components in the BOM.
    [Reverb BOM - Sheet1.csv]
2026-01-25 Revise BOM with new components and pricing
    Updated component list and prices, added LCSC items.
    [Reverb BOM - Sheet1.csv]
2026-02-04 Update JLCPCB Order price in README
    Updated the price for JLCPCB Order and total cost in the Bill Of Materials.
2026-02-04 Modify JLCPCB order price and total in BOM
    Updated JLCPCB order price and total cost in BOM.
    [Reverb BOM - Sheet1.csv]
2026-02-12 Revise BOM quantities and prices in README.md
    Updated quantities and prices for various items in the Bill Of Materials section.
2026-02-12 Revise component prices and links in BOM
    Updated prices and links for various components in the BOM.
    [Reverb BOM - Sheet1.csv]
